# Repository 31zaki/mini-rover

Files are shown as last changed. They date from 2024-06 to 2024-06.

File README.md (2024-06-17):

# Rover mini Project

This project, named "rover-mini," is inspired by my favorite British car, the [Rover Mini](https://en.wikipedia.org/wiki/Mini). The name reflects my respect for this iconic vehicle, known for its compact design and efficient performance, traits that I aim to emulate in this mini robotic rover project.

## Project Overview
The Mini Rover is built using only the chassis of the PiCar-X. For detailed information about the PiCar-X chassis, you can refer to the [official documentation](https://docs.sunfounder.com/projects/picar-x-v20/en/latest/index.html). Note that in this project, the included Robot-HAT is not used. Instead, a custom PCB has been designed for the necessary components and connections. Additionally, custom parts for mounting the PCB were designed using Fusion360.

## Components

- **Raspberry Pi 4B** running Ubuntu Server 22.04 Jazzy.
- **Chassis:** PiCar-X (excluding Robot-HAT expansion board).
- **Cooling:** [GeeekPi Raspberry Pi Low Profile CPU Cooler](https://www.amazon.co.jp/-/en/GeeekPi-Raspberry-Profile-Compatible-Heatsink/dp/B082WV2LL7?th=1).
- **Battery:** [Battery for Raspberry Pi](https://www.amazon.co.jp/gp/product/B0C1GFX5LW/ref=ppx_yo_dt_b_asin_title_o00_s02?ie=UTF8&psc=1).
- **GPIO Expansion:** [GPIO Expansion Board](https://www.amazon.co.jp/gp/product/B072XBX3XX/ref=ppx_yo_dt_b_asin_title_o00_s01?ie=UTF8&th=1).
- **Breadboard** for initial wiring, with plans to design a custom PCB later.

## PCB Design

To streamline the wiring and improve reliability, a custom PCB has been designed using EAGLE. The PCB integrates all necessary components and connections for the Mini Rover.

### EAGLE Design Files

The PCB design files can be found in the `EAGLE/project` directory of this repository. This includes:
- Schematic file (`main_board.sch`)
- Board file (`main_board.brd`)

### EAGLE Libraries

Custom EAGLE libraries have been created for the components used in this project. These libraries are included in the `EAGLE/libraries` directory of this repository.

## Development Environment

**Programming Language:** Python
- **IDE:** Visual Studio Code (VSCode)
- **Connection:** SSH from VSCode to Raspberry Pi

## Wiring Information

### Raspberry Pi 4 (40-pin header) Connections
- **3.3V (Pin 1)** --------------- VCC (BNO055)
- **5V (Pin 2)** --------------- VCC (HC-SR04)
- **GND (Pin 6)** --------------- GND (L298N)
- **GND (Pin 9)** --------------- GND (BNO055)
- **GND (Pin 14)** -------------- GND (Servo Motors)
- **GPIO 2 (Pin 3)** ------------- SDA (BNO055)
- **GPIO 3 (Pin 5)** ------------- SCL (BNO055)
- **GPIO 4 (Pin 7)** ------------- ECHO (HC-SR04) through voltage divider
- **GPIO 17 (Pin 11)** ----------- TRIG (HC-SR04)
- **GPIO 18 (Pin 12)** ----------- ENA (L298N)
- **GPIO 23 (Pin 16)** ----------- IN2 (L298N)
- **GPIO 24 (Pin 18)** ----------- IN1 (L298N)
- **GPIO 25 (Pin 22)** ----------- ENB (L298N)
- **GPIO 27 (Pin 13)** ----------- IN3 (L298N)
- **GPIO 22 (Pin 15)** ----------- IN4 (L298N)
- **GPIO 5 (Pin 29)** ------------ Servo 1 Control
- **GPIO 6 (Pin 31)** ------------ Servo 2 Control
- **GPIO 13 (Pin 33)** ----------- Servo 3 Control

## Goals

- **Programming Practice:** Enhance programming skills, particularly in Python.
- **Electronics Practice:** Gain hands-on experience with electronics and hardware integration.
- **Autonomous Navigation:** Develop a rover that can navigate autonomously using GPS coordinates.
- **ARUCO Tag Recognition:** Implement ARUCO tag recognition for advanced navigation and positioning.

## Getting Started

### Prerequisites

Ensure you have the following installed on your Raspberry Pi:
- Python 3.x
- Git
- Any other dependencies as listed in the `requirements.txt` file (to be added later).

### Installation

Clone this repository to your Raspberry Pi:
    ```bash
    git clone https://github.com/31zaki/mini-rover.git
    cd mini-rover
    ```
Install the necessary Python packages:

Connect to your Raspberry Pi from VSCode via SSH to start development.

## Usage

Detailed usage instructions will be added here as the project progresses.

## Contributing

Contributions are welcome! Please create a fork of the repository, make your changes, and submit a pull request for review.

## License

This project is licensed under the MIT License. See the LICENSE file for details.

## Acknowledgments

- SunFounder for the PiCar-X chassis
- GeeekPi for the cooling solution
- [Battery Supplier](https://www.amazon.co.jp/gp/product/B0C1GFX5LW/ref=ppx_yo_dt_b_asin_title_o00_s02?ie=UTF8&psc=1) for the battery
- [GPIO Expansion Board Supplier](https://www.amazon.co.jp/gp/product/B072XBX3XX/ref=ppx_yo_dt_b_asin_title_o00_s01?ie=UTF8&th=1) for the GPIO expansion

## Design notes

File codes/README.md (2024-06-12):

# Mini Rover Project

This project is a personal initiative aimed at practicing programming and electronics. The ultimate goal is to create an autonomous rover capable of navigating based on GPS coordinates and recognizing ARUCO tags.

## Project Overview

The Mini Rover is built using the chassis of the PiCar-X. For detailed information about the PiCar-X chassis, you can refer to the [official documentation](https://docs.sunfounder.com/projects/picar-x-v20/en/latest/index.html). Please note that in this project, only the chassis of the PiCar-X is used, and the Robot-HAT expansion board is not utilized.

## Components

1. **Raspberry Pi 4B** running Ubuntu Server 22.04 Jazzy.
2. **Chassis:** PiCar-X (excluding Robot-HAT expansion board).
3. **Cooling:** [GeeekPi Raspberry Pi Low Profile CPU Cooler](https://www.amazon.co.jp/-/en/GeeekPi-Raspberry-Profile-Compatible-Heatsink/dp/B082WV2LL7?th=1).
4. **Battery:** [Battery for Raspberry Pi](https://www.amazon.co.jp/gp/product/B0C1GFX5LW/ref=ppx_yo_dt_b_asin_title_o00_s02?ie=UTF8&psc=1).
5. **GPIO Expansion:** [GPIO Expansion Board](https://www.amazon.co.jp/gp/product/B072XBX3XX/ref=ppx_yo_dt_b_asin_title_o00_s01?ie=UTF8&th=1).
6. **Breadboard** for initial wiring, with plans to design a custom PCB later.

## Development Environment

- **Programming Language:** Python
- **IDE:** Visual Studio Code (VSCode)
- **Connection:** SSH from VSCode to Raspberry Pi

## Goals

1. **Programming Practice:** Enhance programming skills, particularly in Python.
2. **Electronics Practice:** Gain hands-on experience with electronics and hardware integration.
3. **Autonomous Navigation:** Develop a rover that can navigate autonomously using GPS coordinates.
4. **ARUCO Tag Recognition:** Implement ARUCO tag recognition for advanced navigation and positioning.

## Getting Started

### Prerequisites

Ensure you have the following installed on your Raspberry Pi:

- Python 3.x
- Git
- Any other dependencies as listed in the `requirements.txt` file (to be added later).

### Installation

1. Clone this repository to your Raspberry Pi:

    ```bash
    git clone https://github.com/31zaki/mini-rover.git
    cd mini-rover
    ```

2. Install the necessary Python packages:

    ```bash
    pip install -r requirements.txt
    ```

3. Connect to your Raspberry Pi from VSCode via SSH to start development.

## Usage

Detailed usage instructions will be added here as the project progresses.

## Contributing

Contributions are welcome! Please create a fork of the repository, make your changes, and submit a pull request for review.

## License

This project is licensed under the MIT License. See the LICENSE file for details.

## Acknowledgments

- SunFounder for the PiCar-X chassis
- GeeekPi for the cooling solution
- [Battery Supplier](https://www.amazon.co.jp/gp/product/B0C1GFX5LW/ref=ppx_yo_dt_b_asin_title_o00_s02?ie=UTF8&psc=1) for the battery
- [GPIO Expansion Board Supplier](https://www.amazon.co.jp/gp/product/B072XBX3XX/ref=ppx_yo_dt_b_asin_title_o00_s01?ie=UTF8&th=1) for the GPIO expansion

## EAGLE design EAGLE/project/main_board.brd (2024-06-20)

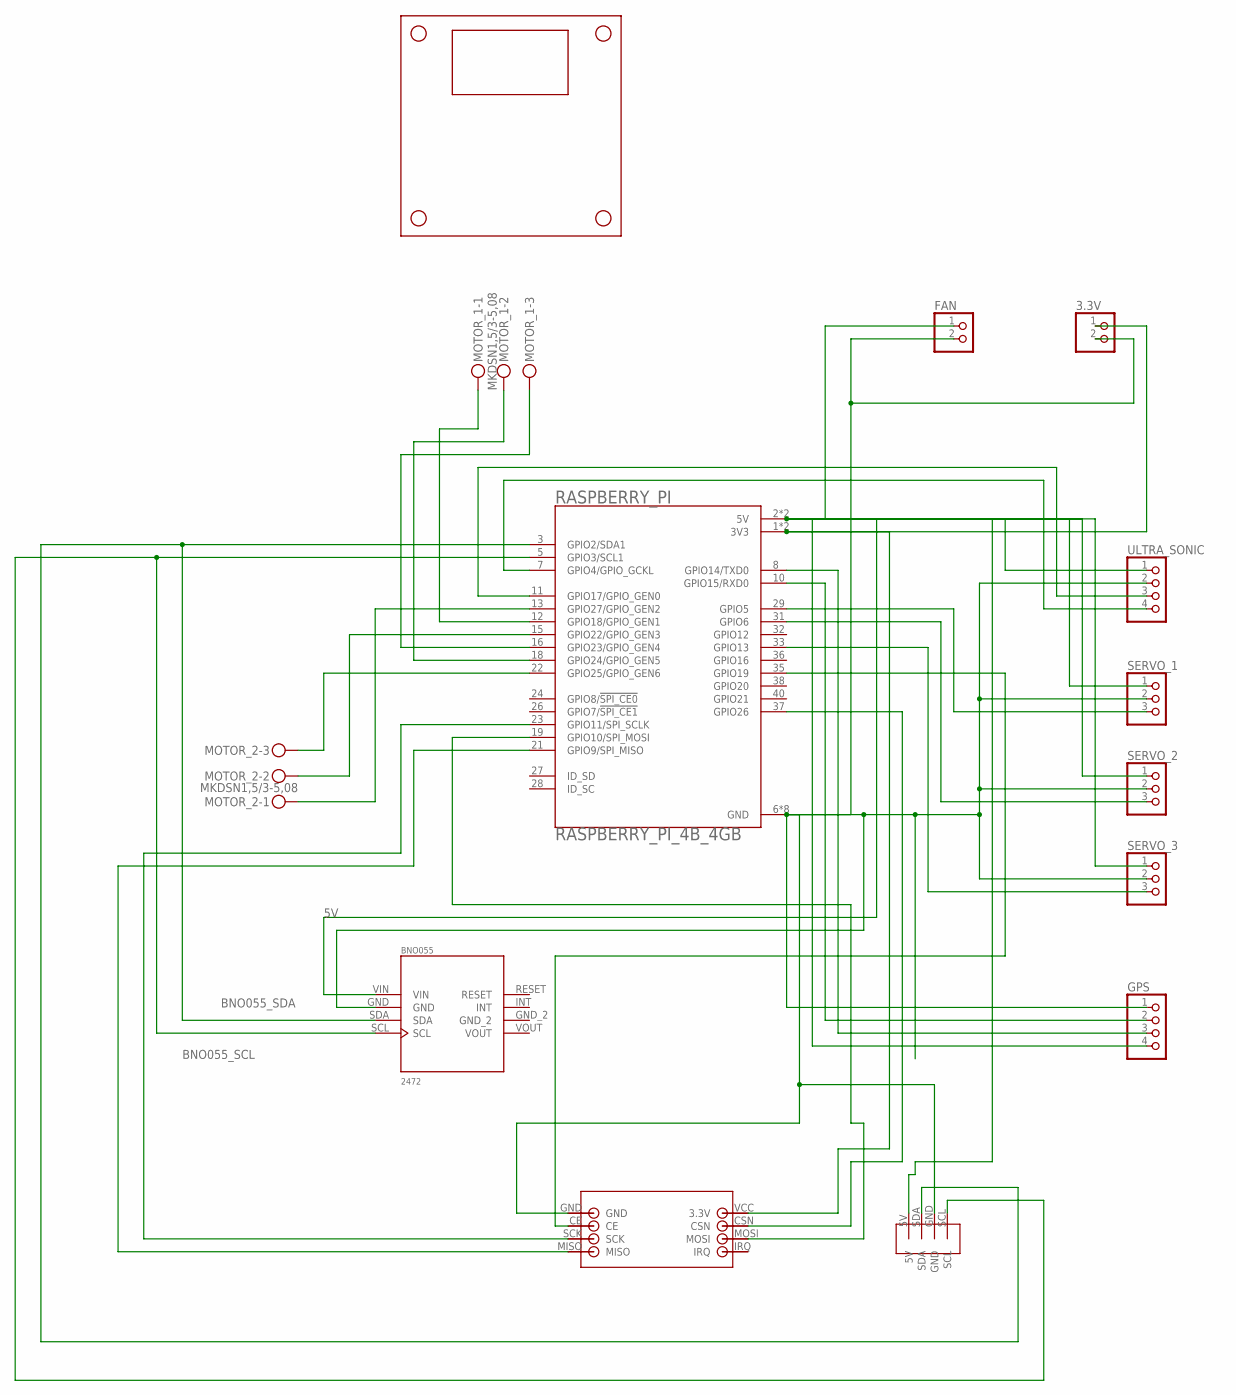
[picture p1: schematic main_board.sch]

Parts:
3.3V: PINHD-1X2; 1X02
BNO055: 2472; MODULE_2472
FAN: PINHD-1X2; 1X02
GPS: PINHD-1X4; 1X04
L298N1: L298N_DRIVER
MOTOR_1, MOTOR_2: MKDSN1,5/3-5,08
NRF24L1: NRF24L01
RASPBERRY_PI: RASPBERRY_PI_4B_4GB; MODULE_RASPBERRY_PI_4B_4GB
SERVO_1, SERVO_2, SERVO_3: PINHD-1X3; 1X03
U$1: DHT20
ULTRA_SONIC: PINHD-1X4; 1X04

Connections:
3.3V: 3.3V.1, NRF24L1.VCC (3.3V), RASPBERRY_PI.1 (3V3), RASPBERRY_PI.17 (3V3)
5V: BNO055.VIN, FAN.1, GPS.4, RASPBERRY_PI.2 (5V), RASPBERRY_PI.4 (5V), SERVO_1.1, SERVO_2.1, SERVO_3.1, U$1.5V, ULTRA_SONIC.1
BNO055_SCL: BNO055.SCL, RASPBERRY_PI.5 (GPIO3/SCL1), U$1.SCL
BNO055_SDA: BNO055.SDA, RASPBERRY_PI.3 (GPIO2/SDA1), U$1.SDA
ENA: MOTOR_1.1, RASPBERRY_PI.12 (GPIO18/GPIO_GEN1)
ENB: MOTOR_2.3, RASPBERRY_PI.22 (GPIO25/GPIO_GEN6)
GND: 3.3V.2, BNO055.GND, FAN.2, GPS.1, NRF24L1.GND, RASPBERRY_PI.6 (GND), RASPBERRY_PI.9 (GND), RASPBERRY_PI.14 (GND), RASPBERRY_PI.20 (GND), RASPBERRY_PI.25 (GND), RASPBERRY_PI.30 (GND), RASPBERRY_PI.34 (GND), RASPBERRY_PI.39 (GND), SERVO_1.2, SERVO_2.2, SERVO_3.2, U$1.GND, ULTRA_SONIC.2
IN1: MOTOR_1.2, RASPBERRY_PI.18 (GPIO24/GPIO_GEN5)
IN2: MOTOR_1.3, RASPBERRY_PI.16 (GPIO23/GPIO_GEN4)
IN3: MOTOR_2.1, RASPBERRY_PI.13 (GPIO27/GPIO_GEN2)
IN4: MOTOR_2.2, RASPBERRY_PI.15 (GPIO22/GPIO_GEN3)
unnamed: NRF24L1.CE, RASPBERRY_PI.35 (GPIO19)
unnamed: NRF24L1.CSN, RASPBERRY_PI.37 (GPIO26)
unnamed: NRF24L1.SCK, RASPBERRY_PI.23 (GPIO11/SPI_SCLK)
unnamed: NRF24L1.MOSI, RASPBERRY_PI.19 (GPIO10/SPI_MOSI)
unnamed: NRF24L1.MISO, RASPBERRY_PI.21 (GPIO9/SPI_MISO)
PWM_SERVO_1: RASPBERRY_PI.29 (GPIO5), SERVO_1.3
PWM_SERVO_2: RASPBERRY_PI.31 (GPIO6), SERVO_2.3
PWM_SERVO_3: RASPBERRY_PI.33 (GPIO13), SERVO_3.3
RX: GPS.3, RASPBERRY_PI.8 (GPIO14/TXD0)
TX: GPS.2, RASPBERRY_PI.10 (GPIO15/RXD0)
ULTRA_SONIC_1: RASPBERRY_PI.7 (GPIO4/GPIO_GCKL), ULTRA_SONIC.4
ULTRA_SONIC_2: RASPBERRY_PI.11 (GPIO17/GPIO_GEN0), ULTRA_SONIC.3

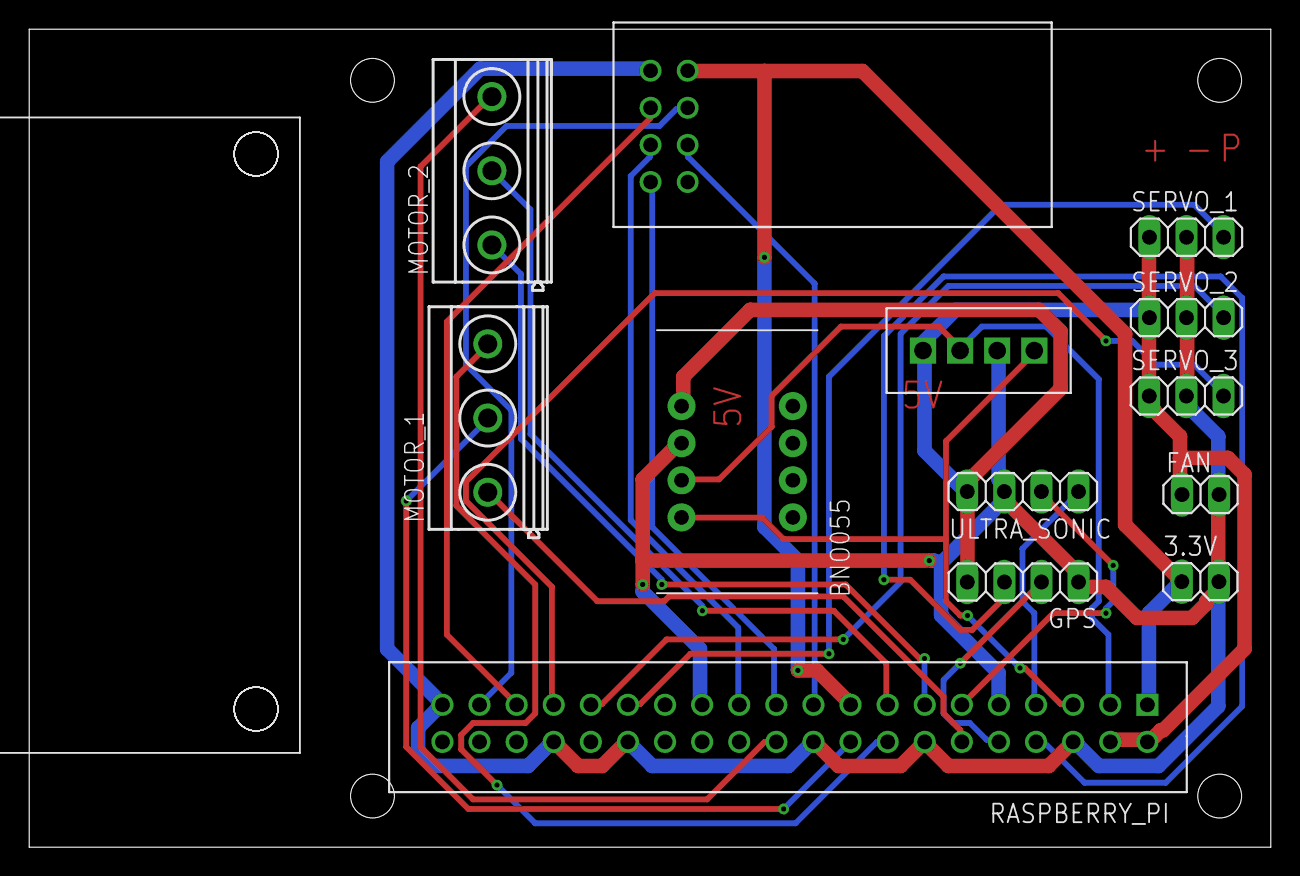
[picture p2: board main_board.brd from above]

Board: 2 copper layers, 85.0 x 56.0 mm, 14 parts (0 on the bottom side), 23 nets.

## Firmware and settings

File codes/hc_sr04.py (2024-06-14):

import RPi.GPIO as GPIO
import time

# GPIO Mode (BOARD / BCM)
GPIO.setmode(GPIO.BCM)

# Set GPIO pins for HC-SR04
GPIO_TRIGGER = 23
GPIO_ECHO = 24

# Set GPIO direction (IN / OUT)
GPIO.setup(GPIO_TRIGGER, GPIO.OUT)
GPIO.setup(GPIO_ECHO, GPIO.IN)

def distance():
    # Set Trigger to HIGH
    GPIO.output(GPIO_TRIGGER, True)

    # Set Trigger after 10µs to LOW
    time.sleep(0.00001)
    GPIO.output(GPIO_TRIGGER, False)

    start_time = time.time()
    stop_time = time.time()

    # Save start time
    while GPIO.input(GPIO_ECHO) == 0:
        start_time = time.time()

    # Save time of arrival
    while GPIO.input(GPIO_ECHO) == 1:
        stop_time = time.time()

    # Time difference between start and arrival
    time_elapsed = stop_time - start_time
    # Multiply with the sonic speed (34300 cm/s)
    # and divide by 2, because there and back
    distance = (time_elapsed * 34300) / 2

    return distance

if __name__ == '__main__':
    try:
        while True:
            dist = distance()
            print(f"Measured Distance = {dist:.1f} cm")
            time.sleep(1)

    except KeyboardInterrupt:
        print("Measurement stopped by User")
        GPIO.cleanup()

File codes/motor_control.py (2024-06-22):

import RPi.GPIO as GPIO

class MotorControl:
    def __init__(self, motor1_pins, motor2_pins, pwm_freq=100):
        self.motor1_in1, self.motor1_in2, self.motor1_ena = motor1_pins
        self.motor2_in3, self.motor2_in4, self.motor2_enb = motor2_pins

        GPIO.setmode(GPIO.BCM)
        GPIO.setwarnings(False)

        GPIO.setup(self.motor1_in1, GPIO.OUT)
        GPIO.setup(self.motor1_in2, GPIO.OUT)
        GPIO.setup(self.motor1_ena, GPIO.OUT)
        GPIO.setup(self.motor2_in3, GPIO.OUT)
        GPIO.setup(self.motor2_in4, GPIO.OUT)
        GPIO.setup(self.motor2_enb, GPIO.OUT)

        self.pwm1 = GPIO.PWM(self.motor1_ena, pwm_freq) #?
        self.pwm2 = GPIO.PWM(self.motor2_enb, pwm_freq)
        self.pwm1.start(0)
        self.pwm2.start(0)

    def stop_motors(self):
        self.pwm1.ChangeDutyCycle(0)
        self.pwm2.ChangeDutyCycle(0)

    def move_forward(self, speed=75):
        GPIO.output(self.motor1_in1, GPIO.HIGH)
        GPIO.output(self.motor1_in2, GPIO.LOW)
        GPIO.output(self.motor2_in3, GPIO.HIGH)
        GPIO.output(self.motor2_in4, GPIO.LOW)
        self.pwm1.ChangeDutyCycle(speed)
        self.pwm2.ChangeDutyCycle(speed)

    def move_backward(self, speed=75):
        GPIO.output(self.motor1_in1, GPIO.LOW)
        GPIO.output(self.motor1_in2, GPIO.HIGH)
        GPIO.output(self.motor2_in3, GPIO.LOW)
        GPIO.output(self.motor2_in4, GPIO.HIGH)
        self.pwm1.ChangeDutyCycle(speed)
        self.pwm2.ChangeDutyCycle(speed)

    def cleanup(self):
        self.stop_motors()
        GPIO.cleanup()

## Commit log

2024-06-12 first commit from raspberry pi
2024-06-12 commit test from raspberry pi
2024-06-12 add motor_test.py
2024-06-13 rearrange folder
    [main_board.brd, main_board.sch]
2024-06-13 design main board PCB by EAGLE
    [main_board.brd, main_board.sch]
2024-06-14 add files to control motors. motor_control.py worked.
2024-06-17 update main board
    [main_board.sch]
2024-06-18 modify board dimension and add GPS module
2024-06-18 separate motor_control and motor_main
2024-06-20 add communication and temp/humid sensor module
    [main_board.brd, main_board.sch]
2024-06-22 add motor_control.py and motor_main.py
